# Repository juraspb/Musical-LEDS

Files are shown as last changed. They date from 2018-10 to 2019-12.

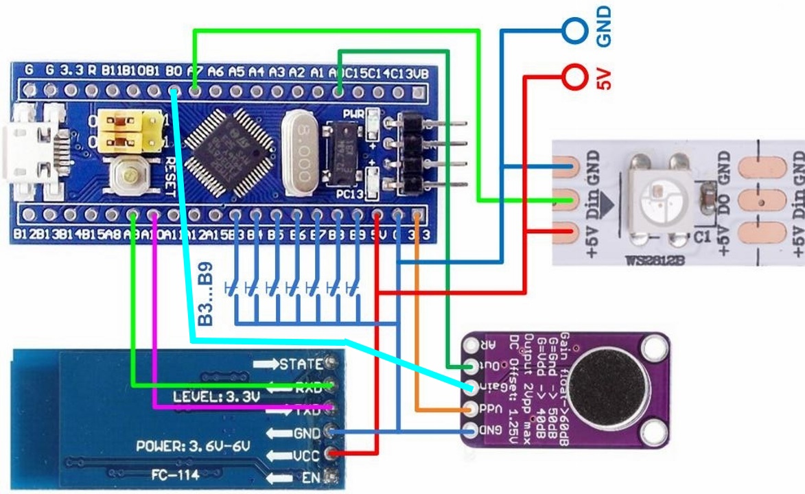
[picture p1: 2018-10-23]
sch.jpg

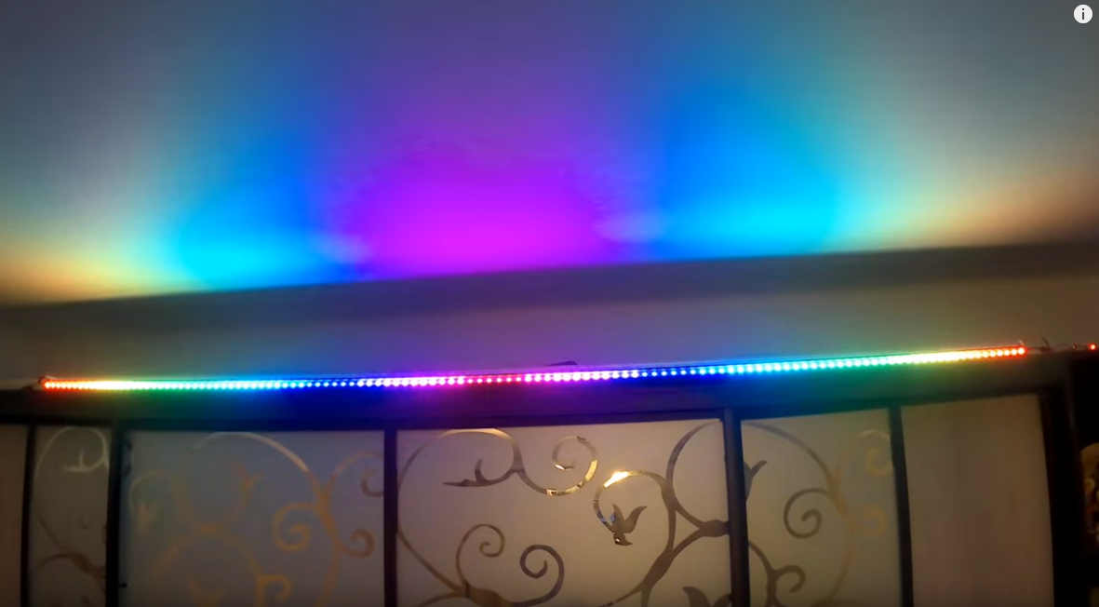
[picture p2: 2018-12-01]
strip/4.png

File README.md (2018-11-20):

# Musical-LEDS

This is a project for self-assembly of the LED strip color music controller.

One of the main features of such controller is that you can easily make it out of cheap and accessible modules, which you may find in popular online stores.
The controller supports LED strips of from 30 to 240 diodes. Before use, you should set the number of diodes in your strip by pressing the LED button. Then save the set value to NVRAM by pressing the SAVE button.
Presented software allows you to enjoy more than 10 built-in musical programs and over 44 dynamical programs. Taking into account all the variations of motion and colors, you will find that overall number of programs exceeds 1000! You can simply choose any program, set up direction of motion, LED strip brightness, motion speed, and comfortable white light color temperature. Moreover, we will continuously release new musical and dynamical programs!
The controller also allows you to make a playlist of dynamical programs. Just add any dynamical program you like to playlist by pressing the ADD button. Using this feature, you can create the playlist of dynamical programs that will alternate each other in order you want with unique motion speed for every program. To clear playlist hold the ADD button for more than 5 seconds. Check the box labeled playlist to start the cyclic playing. Do not forget to save your playlist to NVRAM by pressing the SAVE button.
Using the buttons OFF and CBET, you may turn the LED strip off or turn on simple white lighting at any time.
You may set up your controller from any terminal software using AT commands. To get the command list, use the AT+H command. You can also set colors of the dynamical programs from terminal.
Everything needed to start your amazing LED strip musical experience is to install our firmware on the STM32F103 microcontroller. Assembly instructions and firmware are available to download from the developer’s web site and from the Musical LEDs Facebook group.
Have a nice time!

Video of this controller is presented on YouTube:

https://www.youtube.com/watch?v=DBuPlFtg0Nw

https://www.youtube.com/watch?v=5vanh8qdEC8

https://www.youtube.com/watch?v=MFy6SZ60tzc

1. Download the firmware to the microcontroller.
2. Collect the scheme.
3. Connect the LED strip and power supply.
4. Turn on the power.
5. Set the number of LEDs in the strip. Use the button B9 for this or connect from the PC to the USB port and use the AT commands from any terminal program to configure.
6. Select the desired program and parameters using the buttons or the application for Android.

Enjoy your holiday.

The program for Android is available for download on Google Play:

https://play.google.com/store/apps/details?id=ru.juraspb.cmu.bluetoothchat

Welcome to this project group:

https://www.facebook.com/groups/336136297134996/

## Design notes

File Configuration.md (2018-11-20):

Video configuration run from the terminal program:

https://www.youtube.com/watch?v=0W0cf8ENmME

the same configuration from the Serial  Monitor Arduino IDE

https://vk.com/club171670176?z=video-171670176_456239018%2Fvideos-171670176%2Fpl_-171670176_-2

List of AT commands:

AT

AT+H - Help

AT+L30..240 - Set Led Number

AT+SS - Save settings config

AT+SP - Save play list config

AT+SC - Save program color config

AT+PP - Printing Playlist programs

AT+PC - Printing color used in the subprogram 0..7

AT+D0..127 - Delete the program to play in a loop

AT+DA - Delete all the program to play in a loop

AT+A0..20,0..7,0..240 - Add the program to play in a loop

AT+I0..127,0..29,0..7,0..240 - Insert the program to play in a loop

AT+B0..256 - Set the brightness for dynamic programs

AT+M0..256 - Set the brightness for musical programs

AT+T10..240 - Set tempo

AT+C0[1] - 0 - disable CLAP, 1 - enable CLAP

AT+W0..7,0..5,0..112 - Write subprogram,color number,new color

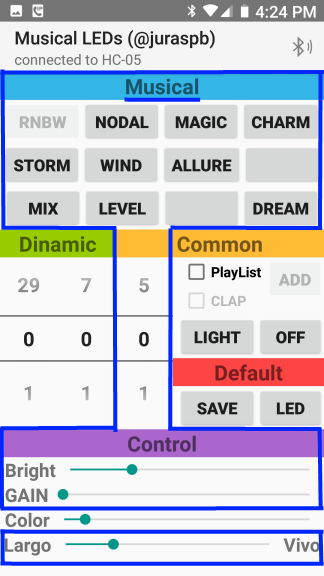
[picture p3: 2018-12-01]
android/1musical.png

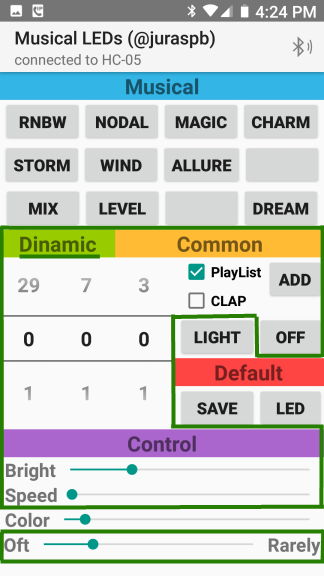
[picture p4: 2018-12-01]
android/1playlist.png

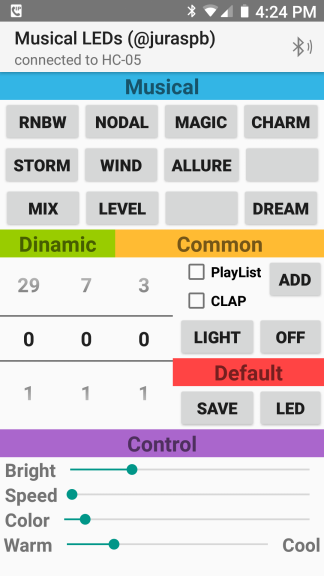
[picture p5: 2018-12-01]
android/1connected.png

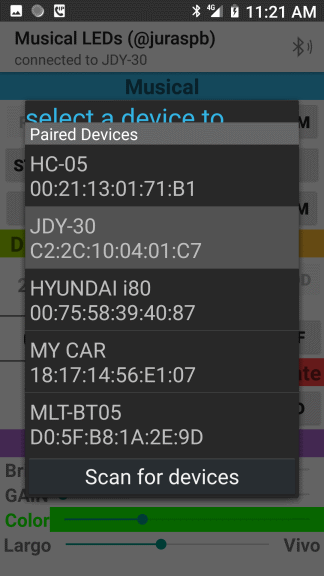
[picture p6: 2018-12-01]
android/2e.png

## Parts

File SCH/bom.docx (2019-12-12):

N | | | | | SMD | TH
1 | C1,C6 | 47.0uFx16V | Capacitor, SMD, 1210, 3225Metric | 2 | 2
2 | C2,C5,C7,C12 | 0.1uFx16V | Capacitor, SMD, 0603, 1608Metric | 4 | 6
3 | C3,C4 | 22pFx16V | Capacitor, SMD, 0603, 1608Metric | 2 | 8
4 | C8,C9,C10 | 1uFx16V | Capacitor, SMD, 0603, 1608Metric | 3 | 11
5 | C13 | 0.47uFx16V | Capacitor, SMD, 0603, 1608Metric | 1 | 12
6 | C14 | 2.2uFx16V | Capacitor, SMD, 0603, 1608Metric | 1 | 13
7 | C11 | 470nFx16V | Capacitor, SMD, 0603, 1608Metric | 1 | 14
8 | J2 | Linear | Connector, Audio Jack, 3.5mm, PJ320D, Horizontal | 1 | 15
10 | J4 | POWER | Phoenix Contact, MC 1,5 3-G-3.81, P3.81mm Horizontal | 1 | | 3
11 | J7 | USB B Micro | Connector, USB Micro B, Molex 47346-0001 | 1 | 16
12 | R1,R9 | 47K | Resistor, SMD, 0603, 1608Metric | 2 | 18
13 | R2 | 100K | Resistor, SMD, 0603, 1608Metric | 1 | 19
14 | R3,R4,R16 | 1K | Resistor, SMD, 0603, 1608Metric | 3 | 22
15 | R5,R6,R7 | 4K7 | Resistor, SMD, 0603, 1608Metric | 3 | 25
16 | R8 | 100 | Resistor, SMD, 0603, 1608Metric | 1 | 26
17 | R10 | 1K5 | Resistor, SMD, 0603, 1608Metric | 1 | 27
18 | R11,R12 | 22 | Resistor, SMD, 0603, 1608Metric | 2 | 29
19 | R13 | 100K | Resistor, SMD, 0603, 1608Metric | 1 | 30
20 | R14 | 150K | Resistor, SMD, 0603, 1608Metric | 1 | 31
21 | R15 | 2K2 | Resistor, SMD, 0603, 1608Metric | 1 | 32
22 | U1 | AP1117-33 | SMD, SOT-223-3 | 1 | 33
23 | U2 | STM32F103C8T6 | LQFP-48, 7x7mm, P0.5mm | 1 | 34
24 | U3 | AD8603 | SMD, TSOT-23-5 | 1 | 35
25 | U4 | 74LVC1G125 | SMD, SOT-23-5 | 1 | 36
27 | D1 | HC-05 | HC-05 bluetooth controller | 1 | 38
28 | VD1 | LED GREEN | LED GREEN, SMD, 0603, 1608Metric | 1 | 39
29 | Y1 | Crystal | Crystal 8MHz, SMD, 5032, 2Pin, 5.0x3.2mm | 1 | 40
| | | | ALL | 40 | 3

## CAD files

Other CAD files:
SCH/stm32mc.wrl.sldprt
SCH/stm32mc.sldprt

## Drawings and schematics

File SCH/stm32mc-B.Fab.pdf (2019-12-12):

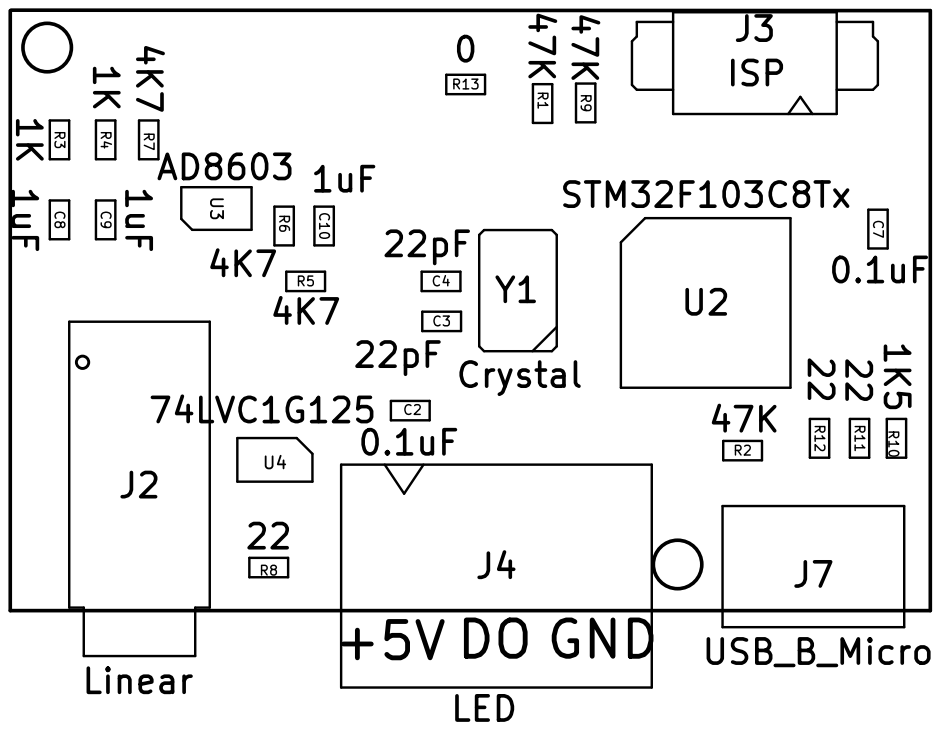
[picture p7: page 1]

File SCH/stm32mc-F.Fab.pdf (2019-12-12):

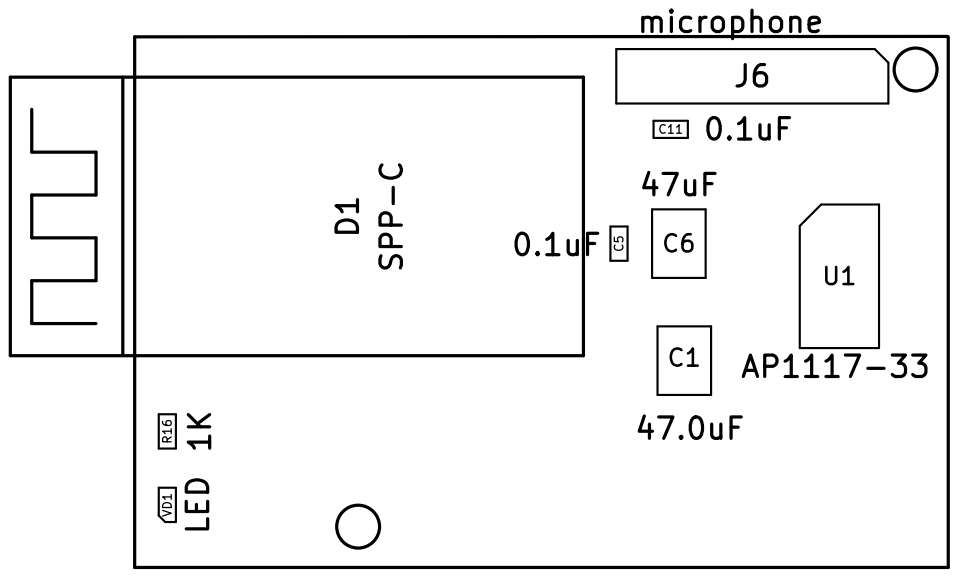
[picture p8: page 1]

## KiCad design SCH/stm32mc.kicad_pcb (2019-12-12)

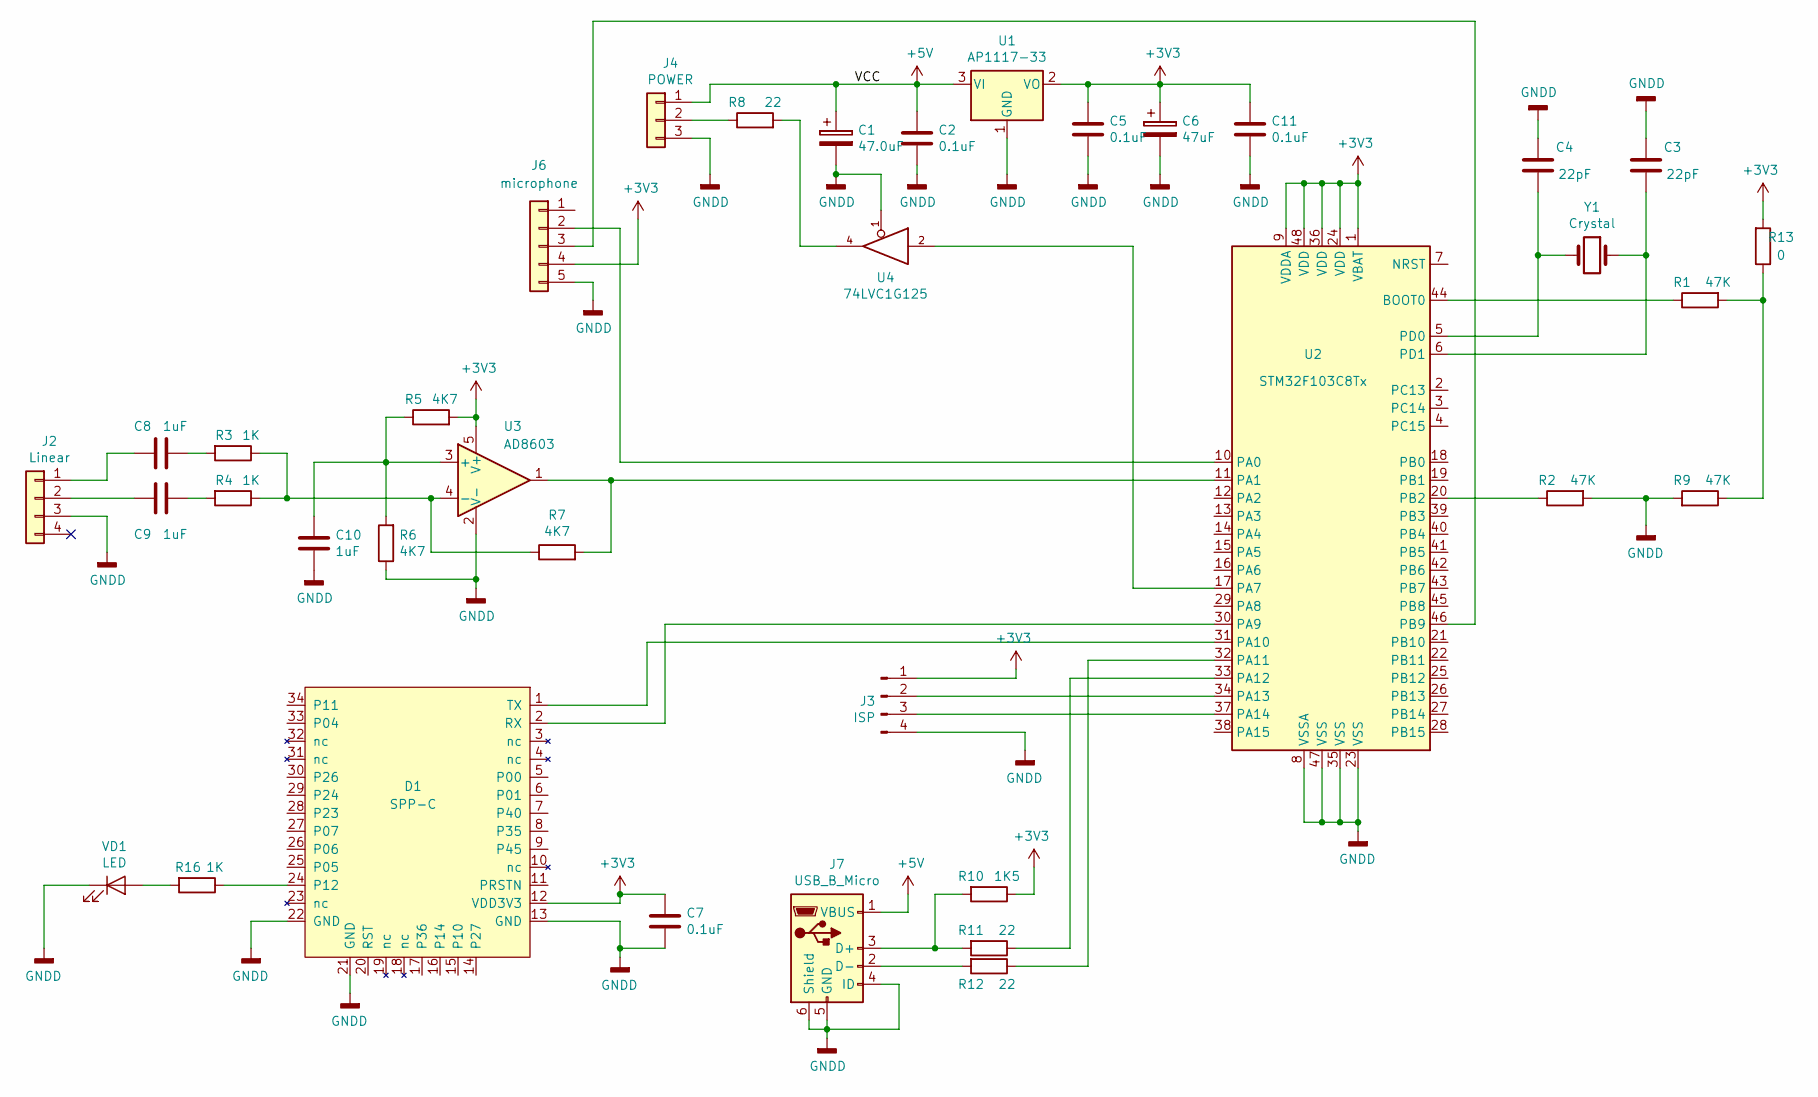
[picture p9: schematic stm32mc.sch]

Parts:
C1: 47.0uF; C_1210_3225Metric
C2, C5, C7, C11: 0.1uF; C_0603_1608Metric
C3, C4: 22pF; C_0603_1608Metric
C6: 47uF; C_1210_3225Metric
C8, C9, C10: 1uF; C_0603_1608Metric
D1: SPP-C; SPP-C_cmu
J2: Linear; Jack_3.5mm_PJ320D_Horizontal
J3: ISP; Molex_PicoBlade_53261-0471_1x04-1MP_P1.25mm_Horizontal
J4: POWER; PhoenixContact_MC_1,5_3-G-3.81_1x03_P3.81mm_Horizontal
J6: microphone; PinHeader_1x05_P2.54mm_Vertical
J7: USB_B_Micro; USB_Micro-B_Molex_47346-0001
R1, R2, R9: 47K; R_0603_1608Metric
R3, R4, R16: 1K; R_0603_1608Metric
R5, R6, R7: 4K7; R_0603_1608Metric
R8, R11, R12: 22; R_0603_1608Metric
R10: 1K5; R_0603_1608Metric
R13: 0; R_0603_1608Metric
U1: AP1117-33; SOT-223-3_TabPin2
U2: STM32F103C8Tx; LQFP-48_7x7mm_P0.5mm
U3: AD8603; TSOT-23-5
U4: 74LVC1G125; SOT-23-5_HandSoldering
VD1: LED; LED_0603_1608Metric
Y1: Crystal; Crystal_SMD_5032-2Pin_5.0x3.2mm

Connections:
+3V3: C5.1, C6.1, C7.1, C11.1, D1.12 (VDD3V3), J3.1, J6.4, R5.2, R10.1, R13.2, U1.2 (VO), U2.1 (VBAT), U2.9 (VDDA), U2.24 (VDD), U2.36 (VDD), U2.48 (VDD), U3.5 (V+)
+5V: C1.1, C2.1, J4.1, J7.1 (VBUS), U1.3 (VI), U4.5 (VCC)
GND: U4.3 (GND)
GNDD: C1.2, C2.2, C3.1, C4.1, C5.2, C6.2, C7.2, C10.2, C11.2, D1.13 (GND), D1.21 (GND), D1.22 (GND), J2.3, J3.4, J4.3, J6.5, J7.4 (ID), J7.5 (GND), J7.6 (Shield), R2.2, R6.1, R9.2, U1.1 (GND), U2.8 (VSSA), U2.23 (VSS), U2.35 (VSS), U2.47 (VSS), U3.2 (V-), U4.1, VD1.1 (K)
unnamed: C3.2, U2.6 (PD1), Y1.1
unnamed: C4.2, U2.5 (PD0), Y1.2
unnamed: C8.1, J2.1
unnamed: C8.2, R3.2
unnamed: C9.1, J2.2
unnamed: C9.2, R4.2
unnamed: C10.1, R5.1, R6.2, U3.3 (+)
unnamed: D1.1 (TX), U2.31 (PA10)
unnamed: D1.2 (RX), U2.30 (PA9)
unnamed: D1.24 (P12), R16.1
unnamed: J3.2, U2.34 (PA13)
unnamed: J3.3, U2.37 (PA14)
unnamed: J4.2, R8.1
unnamed: J6.2, U2.10 (PA0)
unnamed: J6.3, U2.46 (PB9)
unnamed: J7.2 (D-), R12.2
unnamed: J7.3 (D+), R10.2, R11.2
unnamed: R1.1, U2.44 (BOOT0)
unnamed: R1.2, R9.1, R13.1
unnamed: R2.1, U2.20 (PB2)
unnamed: R3.1, R4.1, R7.1, U3.4 (-)
unnamed: R7.2, U2.11 (PA1), U3.1
unnamed: R8.2, U4.4
unnamed: R11.1, U2.33 (PA12)
unnamed: R12.1, U2.32 (PA11)
unnamed: R16.2, VD1.2 (A)
unnamed: U2.17 (PA7), U4.2

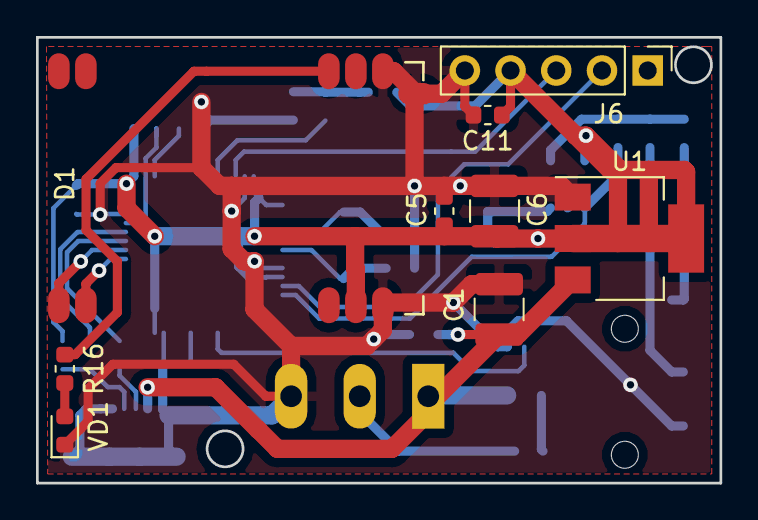
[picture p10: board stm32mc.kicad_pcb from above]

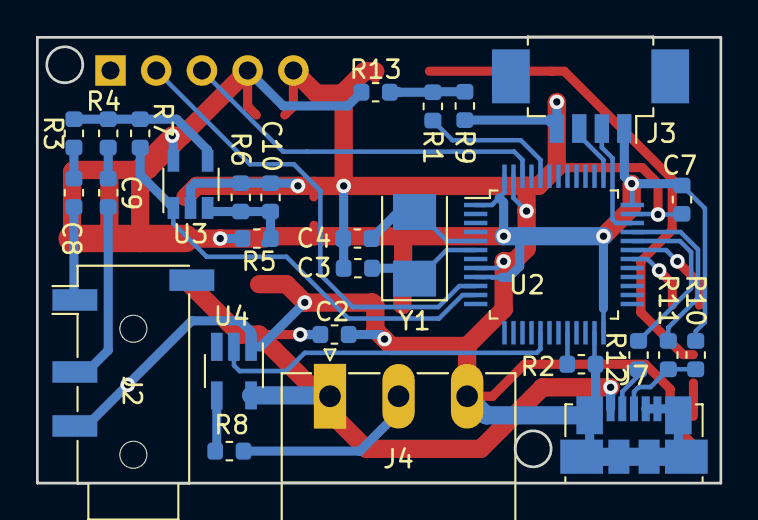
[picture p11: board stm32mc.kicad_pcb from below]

Board: 2 copper layers, 38.0 x 24.8 mm, 37 parts (28 on the bottom side), 30 nets.

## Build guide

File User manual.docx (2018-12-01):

Hi!

Here I present my autonomous musical lighting assembly instructions. STM32F103C8T6 microcontroller does all the processing of audio stream. You can change color and dynamical programs via Bluetooth using your smartphone and/or using hardware buttons. You are welcome to download needed software for Android from the Google Play Store (https://play.google.com/store/apps/details?id=ru.juraspb.cmu.bluetoothchat&hl=ru).

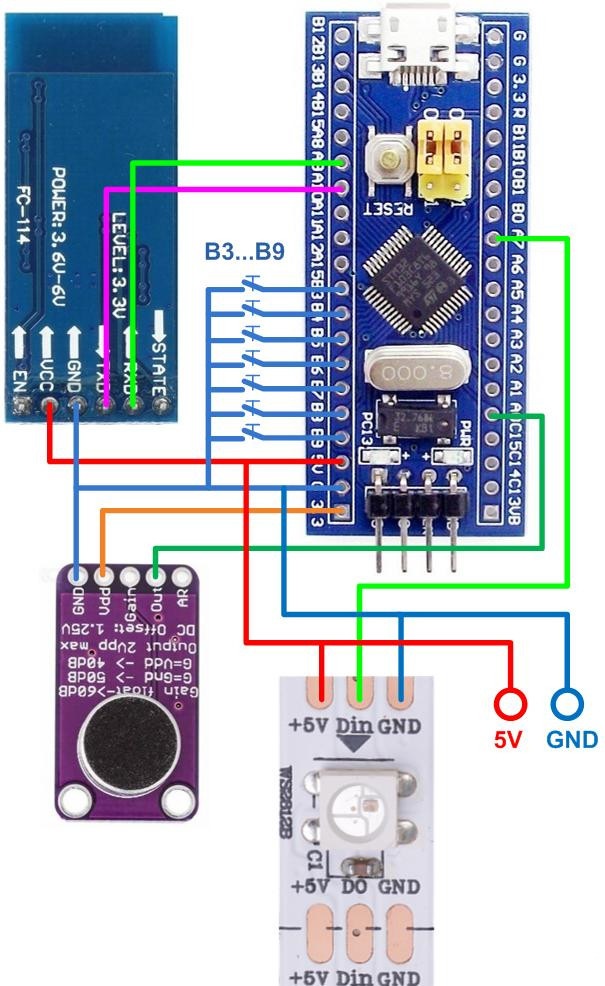
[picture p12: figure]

Wiring diagram

You will need:

1. STM32 mini board (http://shopeasy.by/cashback/view/pdsksg4m6wzm5yxq5dphrkkkfzbjtb4u/)

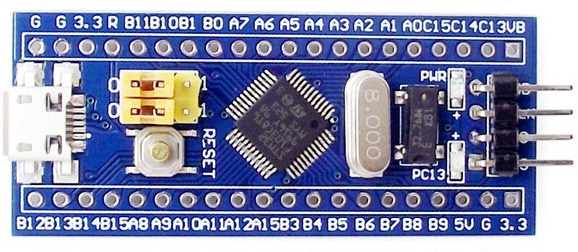
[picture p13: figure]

2. Bluetooth module (http://shopeasy.by/cashback/view/pdsksg4m6wzm5yxq5dphrkkkfzbjtb4u/)

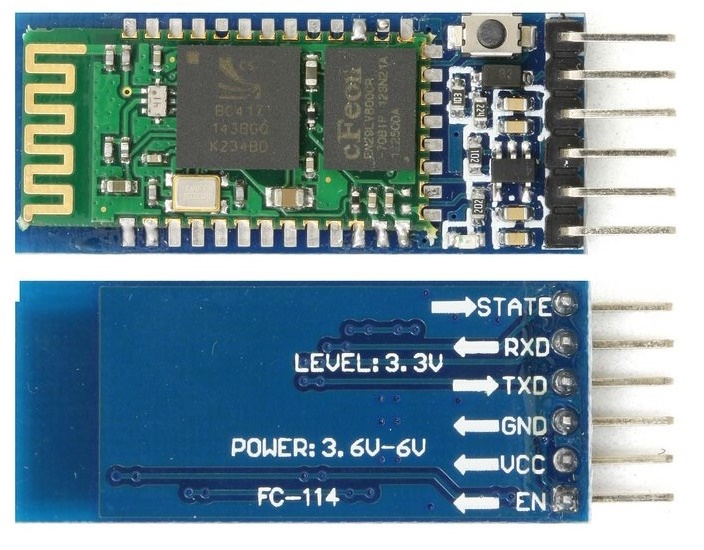
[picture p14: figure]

3. Microphone sensor module (http://shopeasy.by/cashback/view/pdsksg4m6wzm5yxq5dphrkkkfzbjtb4u/)

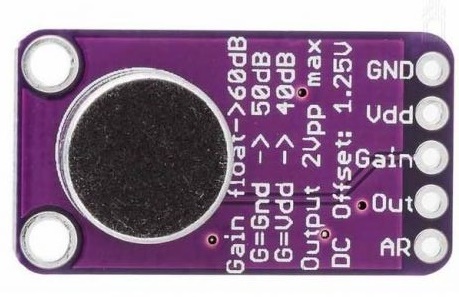
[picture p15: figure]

4. LED strip (https://ru.aliexpress.com/item/DC5V-WS2812B-1-4-5-30-60-74-96-144-s/32832420003.html)

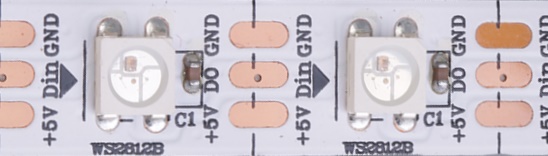
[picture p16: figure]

5. Power supply DC 5V min current=(((LEDsnumber*60)/1000)*1.2)A
6. Connectors for strip and power supply. You can take one for connecting to the LED strip from its output end (Dout).

If you do not have a microphone or do not want to use it, you can connect the signal to the controller from the audio output. Use for this simple scheme shown in the figure.

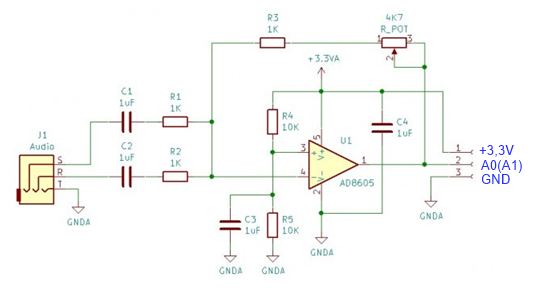
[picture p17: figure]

You can also use both options using the inputs A0 and A1 of the controller. Use A15 to select the audio source. If contact A15 is connected to GND, then the program will take the audio signal from input A1, if A15 is left unconnected, then the program will take the audio signal from input A0.

Each circuit has its own pros and cons. For the line input, you will need a cable; on the other hand, microphone captures external sounds. You can use both diagrams.

FIRMWARE PROGRAMMING

STM32 programming is done through the USB-ART adapter using the Flash loader demonstrator (https://www.st.com/en/development-tools/flasher-stm32.html) program. There are several descriptions of the STM32 programming process. You are welcome to choose the description you find clearer.

New firmware for the STM32 microcontroller is always available for download from Google Drive (https://drive.google.com/open?id=1Hz0A7ePngtKswKY_SBIgg0VM0KC1rL70).

For controlling STM32, you may use the hardware buttons, the terminal program via the built-in micro USB, and the Android application.

MUSICAL LEDs USER MANUAL

Software MUSICAL LEDs (https://play.google.com/store/apps/details?id=ru.juraspb.cmu.bluetoothchat&hl=ru) is available for Android on Google Play.

1. Connection to the controller

Touch the Bluetooth in the top right corner of the screen of your smartphone. Choose your Bluetooth controller from the list.

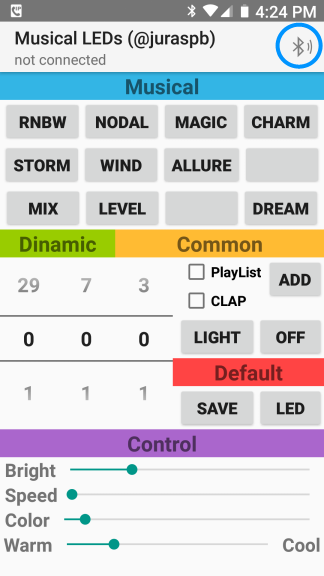
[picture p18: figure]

Wait for connection.

2. Selecting program, direction (mode), brightness, motion speed

Select musical program using buttons in the Musical part of the screen, or dynamic program using first two scrolling bars under the Dynamic label. Set comfortable brightness, gain, color and motion speed using sliders in the Settings part.


Dynamic programm control | Musical program control

You can set the motion direction or performance mode for programs without directed LED light motion (not present in all programs so far) both for musical and dynamic programs using the third scrolling bar in the Dynamic part of the screen.

3. Creating your own dynamic programs playlist

You can create a list of dynamical programs that will be played in rotation. To do this, consistently select dynamic programs, subprograms, directions (modes), and motion speed, adding programs you like to playlist by hitting the ADD button. After you are done, save programs by hitting SAVE. Max. number of programs in the list is 80.

Further, you can add programs to playlist at any time by hitting ADD. Do not forget to save your new playlist by hitting SAVE.

To start playing your playlist check the box LIST.

To clear playlist hold the ADD button for more than 5 sec.

4. Changing color design

For simple dynamic programs (from 3 to 29) that change color depending on subprogram (second scroll bar) you can set your own colors.

You have probably noticed that the zero subprogram uses red V and yellow V as the first two colors in all programs.

You can view all colors used in subprograms from terminal using AT+PC (print color) command.

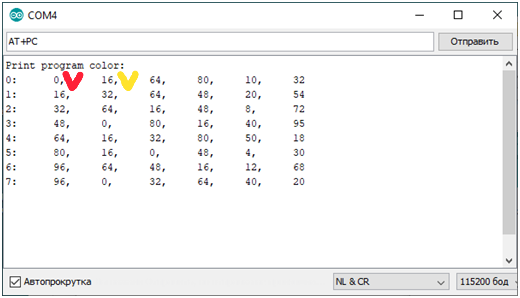
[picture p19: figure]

Each line represents the subprogram number (the first character) followed by six color numbers.

Simple dynamic programs use different number of colors from one to six. In the main, colors can be changed for subprograms from zero to six, and seventh subprogram consistently plays subprograms from zero to six.

If the program uses just one color then it is the first color in the line. If the program uses two colors then these are the first two colors in the line, and so on.

Color numbers

0 | … | 16 | ... | 32 | … | 48 | … | 64 | … | 80 | ..95
Red | … | Yellow | … | Green | … | bluish green | … | Dark blue | … | Violet | …

You can change colors both from terminal and from the Android software.

Changing colors from the Android software

1. Set the second scroll bar to a position from zero to six depending on which subprogram colors you want to change.

Program number (0 to 29) can be set to any value. The selected subprogram of the selected program starts playing

2.

2.1. Set static color by the color slider. Select the color you want to use first in selected subprogram.

All LEDs light up with selected light.

2.2. Hit the ADD button. Color will be added to the selected subprogram.

2.3. Again, set static color you want to use second by the color slider.

All LEDs light up with selected light.

2.4. Hit the ADD button. The second color will be added to the selected subprogram...

...repeat actions 2.1 – 2.2 to set colors from third to sixth. It is necessarily to set all six colors.

Note: In the static color mode, pressing the ADD button changes to the current static color, the color of the last installed dynamic program (the program that was before the static color was set). The 6 color always changes, shifting the colors of the program to the beginning. For example, entering in a row 6 colors, old colors numbers new letters: 123456, ‘r’-> 23456r, ‘g’->3456rg, ‘b’->456rgb, ‘m’->56rgbm, ‘s’->6rgbms, ‘v’->rgbmsv, so after entering 6 colors of color 123456, they will be replaced by rgbmsv

Check the color in all programs. If you are satisfied, hit SAVE to save color settings.

Have a nice time!

The following chapters are not needed for ordinary use, but if you want to customize the controller to your liking, the firmware allows you to do this.

Changing colors from terminal software

You can use any terminal program including ARDUINO IDE port monitor.

From terminal software, you can set:

1. Number of LEDs in the strip;

2. Colors of dynamic programs;

3. Brightness level of both musical and dynamical programs;

4. Motion speed;

5. Dynamic programs playlist.

In addition, you are able to save parameters from terminal.

Setting up is done via AT commands. The list of AT commands is constantly growing and is available for specific firmware by AT+H command.

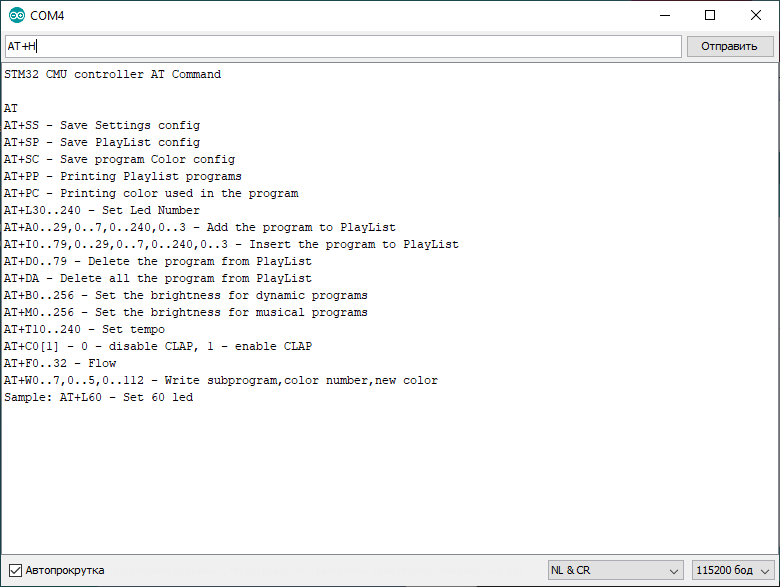
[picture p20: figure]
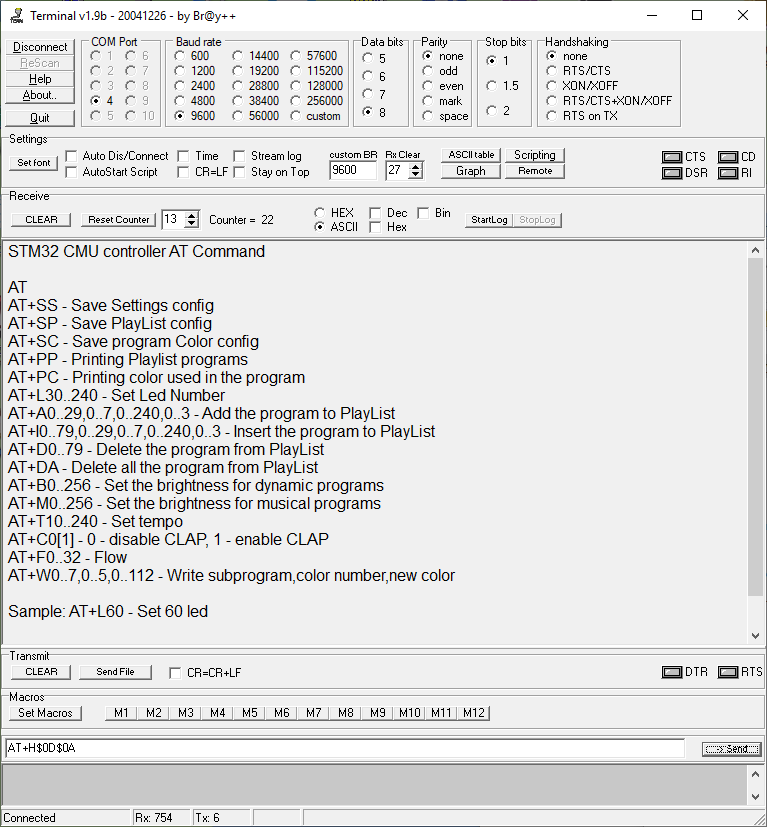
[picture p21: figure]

The main takeaways for color choice

1. Dynamic programs from third to twenty-ninth (exceptions are present) have seven color subprogram modes each, plus one combinative program. Subprograms are set with the second scroll bar and their numbers are from zero to seven. The seventh one is combinative, and it alternately picks colors of programs from zero to six.
2. Max. number of colors used in dynamic programs from third to twenty-ninth equals six.
3. You can view list of dynamical subprograms using AT+PC command

For example:
0: 0, 15, 31, 47, 63, 79
1: 80, 70, 60, 50, 40, 30
……..
Thus in all programs from third to twenty-ninth
by default zero program uses colors 0, 15, 31, 47, 63, 79 (red, yellow … )
by default first program uses colors 80, 70, 60, 50, 40, 30
……

4. Colors are as on rainbow: 0-red,…..,16-yellow,….,32-green,….,48-bluish green,….,64-dark blue,….,80-violet,95-red,112-white 100%,…..,128-white 0%(black).

For setting your colors from terminal, select dynamic program that uses all six colors and then select the dynamic program n, whose colors you would like to change.

Set the first color typing AT+ Wn,0,c1, where c1 is the color number from 0 to 128
Set the second color typing AT+ Wn,0,c2, where c2 is the color number from 0 to 128 Set the third color typing AT+ Wn,0,c1, where c1 is the color number from 0 to 128
…..
Set the sixth color typing AT+ Wn,0,c6, where c6 is the color number from 0 to 112

During the set up, colors are changed to yours.

You can also change colors from the Android software.

To do this, select dynamic program that uses all six colors and then select the dynamic program, whose colors you want to change. You will be unable to view the dynamic program playing until the end of the setting.
1. Set the first static color using slider and hit the ADD button.
2. Repeat these actions for remaining six colors

It is necessary to set up all six colors. After you are done, play your subprogram and make sure that colors you selected are now used. If you like this color solution, SAVE it.

Setting up the hardware buttons (contacts)

Buttons purpose:
B9 – saving all parameters as defaults when turn the power on
B8 – setting the number of active LEDs in the strip (discretely)
B7 – dynamic program selection;
B6 – musical program selection;
B5 – turning ON/OFF the dynamic programs changing mode;
B4 – setting up the LED strip brightness.
B3 – setting up the program speed.

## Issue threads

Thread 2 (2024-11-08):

Want to say Thank You

Juris3D, 2024-11-08:
Хочу сказать Вам очень большое спасибо за эту Вашу разработки цветомузыки на STM32. Да, "лучше поздно чем никогда". Я первый раз повторял давно, но тогда интерес пропал, не углублялся особо. Теперь когда "въехал" во все нюансы установок (чувствительность по частоным каналам через service! Super) и возможностей - замечательно. Я пока на старой прошивке, но буду на другом STM32 пробовать и ту что появилась позднее, с дополнительными pwm выходами.
Ещё раз - Спасибо.
P.S.: маленький вопрос, возможно ли установка "других" вариантов количества светодиодов? Конкретно, 64 и 256? Работа Вашей конструкции хорошо смотритса также на матрицах (8х8, 16х16).
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

juraspb, 2024-11-08:
HiЦветомузыка в каталоге RuStorerustore.ruThe program is provided as is. At the moment I am busy with work projects. Thank you for your interest in the device. I am glad that you like my device.YuriyОтправлено с iPad8.11.2024, в 13:54, Juris Perkons ***@***.***> написал(а):
Хочу сказать Вам очень большое спасибо за эту Вашу разработки цветомузыки на STM32. Да, "лучше поздно чем никогда". Я первый раз повторял давно, но тогда интерес пропал, не углублялся особо. Теперь когда "въехал" во все нюансы установок (чувствительность по частоным каналам через service! Super) и возможностей - замечательно. Я пока на старой прошивке, но буду на другом STM32 пробовать и ту что появилась позднее, с дополнительными pwm выходами.
Ещё раз - Спасибо.
P.S.: маленький вопрос, возможно ли установка "других" вариантов количества светодиодов? Конкретно, 64 и 256? Работа Вашей конструкции хорошо смотритса также на матрицах (8х8, 16х16).
MusicLEDs_STM32.jpg (view on web)

—Reply to this email directly, view it on GitHub, or unsubscribe.You are receiving this because you are subscribed to this thread.Message ID: ***@***.***>

Juris3D, 2024-11-09:
Thank You for answering! I got Android apk from one of "apk downloads" sites, so I wouldnt need to try to register on ru marketplace. As I said, device and accompaning software is great! Only strong wish is, that would be possible to set "count of LEDs" as multiple of "8". Right now, can not set values like "64", "256", to fill popular WS2812 matrixes.
I see on your Github newer lights projects (ESP32) projects, will be following possible updates! :) Best wishes.

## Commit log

2018-10-23 assembly drawing file loaded
2018-12-01 Musical leds
    Musical leds
2018-12-01 view
    View Musical LEDs
2019-12-10 Add files via upload
    new
    [Service.cfg]
2019-12-12 Add files via upload
    Schematic and PCB
    [stm32mc-B.Adhes.gbr, stm32mc-B.CrtYd.gbr, stm32mc-B.Cu.gbr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]
